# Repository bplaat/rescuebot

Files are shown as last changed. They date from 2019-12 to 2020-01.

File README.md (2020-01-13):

# RescueBot
Technische Informatica - Project 2 (RescueBot) - Group 5

## Slave to Master protocol
Values to receive from nano:

- `distance_to_object` represents the distance the the object in front of the car in cm
- `distance_to_left` represents the distance to first left object / wall in cm
- `distance_to_right` represents the distance to first right object / wall in cm
- `distance_to_ground` represents the distance to the ground in cm
- `ir_left` the value of the ir sensor on the left site as boolean (1 means border found)
- `ir_right` the value of the ir sensor on the right site as boolean (1 means border found)

```
struct slave_to_master {
    uint8_t distance_to_object;
    uint8_t distance_to_left;
    uint8_t distance_to_right;
    uint8_t distance_to_ground;
    uint8_t ir_left;
    uint8_t ir_right;
};
```

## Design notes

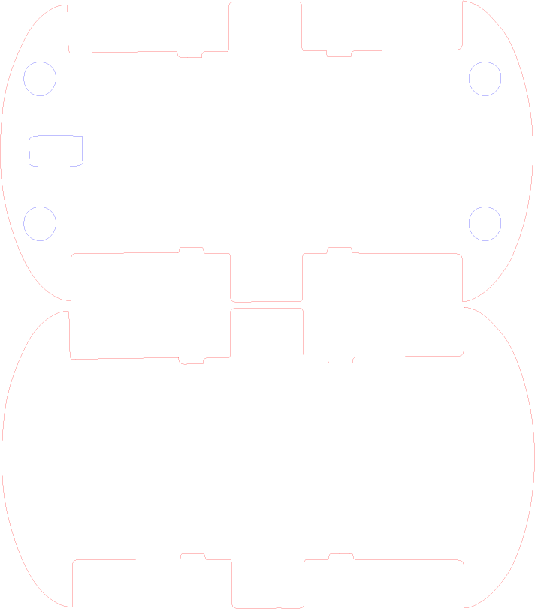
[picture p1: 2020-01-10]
documents/auto design revised.png

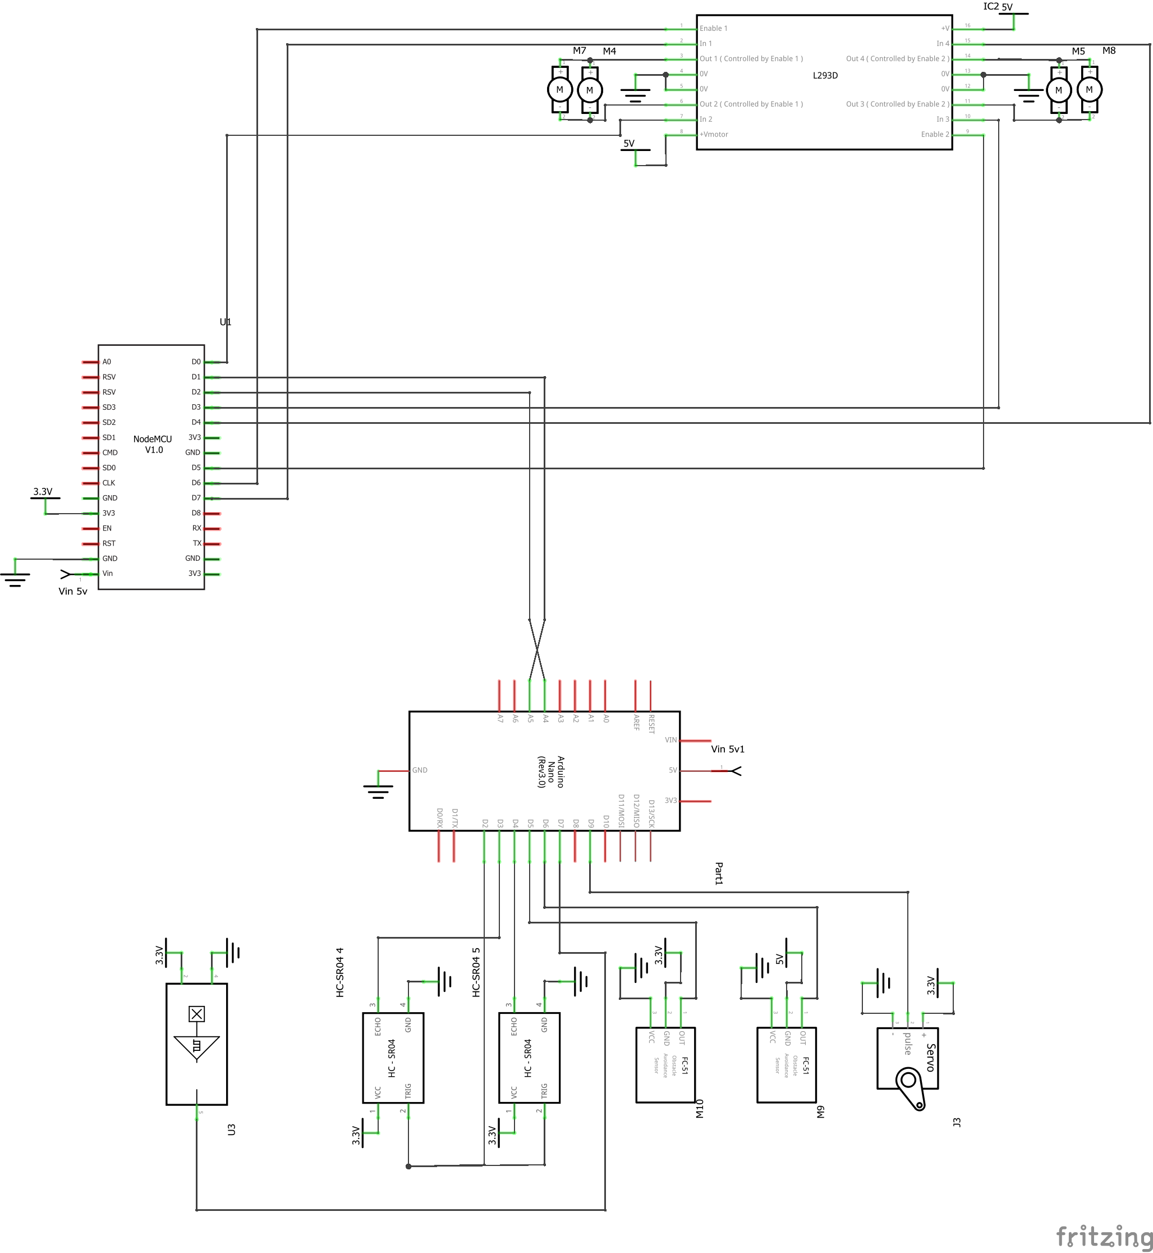
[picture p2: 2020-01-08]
documents/scheme.png

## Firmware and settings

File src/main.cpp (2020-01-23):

// Include the libraries, the config and the website headers
#include <Arduino.h>
#include <ESP8266WiFi.h>
#include <ESP8266WebServer.h>
#include <WebSocketsServer.h>
#include <ArduinoJson.h>
#include <Wire.h>
#include "config.hpp"
#include "website.hpp"

// #############################################################################
// ############################# I2C COMMUNICATION #############################
// #############################################################################

// The i2c variables
#define I2C_ADDRESS 10
#define REQUEST_TIMEOUT 250
#define PROTOCOL_REQUEST_MESSAGE_LENGTH 6
#define PROTOCOL_BORDER_NOT_FOUND 0
#define PROTOCOL_BORDER_FOUND 1

uint32_t request_time;

uint8_t distance_to_object;
uint8_t distance_to_left;
uint8_t distance_to_right;
uint8_t distance_to_ground;
uint8_t ir_left;
uint8_t ir_right;

// A function that request the data and updates some variables
void update_data_from_slave() {
    if (Wire.requestFrom(I2C_ADDRESS, PROTOCOL_REQUEST_MESSAGE_LENGTH) == PROTOCOL_REQUEST_MESSAGE_LENGTH) {
        distance_to_object = Wire.read();
        distance_to_left = Wire.read();
        distance_to_right = Wire.read();
        distance_to_ground = Wire.read();
        ir_left = Wire.read();
        ir_right = Wire.read();

        #ifdef DEBUG
            printf("distance_to_object: %d, distance_to_left: %d, distance_to_right: %d, distance_to_ground: %d, ir_left: %d, ir_right: %d\n",
                distance_to_object, distance_to_left, distance_to_right, distance_to_ground, ir_left, ir_right);
        #endif
    }
}

// A function that ints the i2c and gets the data
void i2c_init() {
    request_time = millis();
    Wire.begin();
    update_data_from_slave();
}

// #############################################################################
// ############################### MOTOR PINS ##################################
// #############################################################################

// The motor pins
#define MOTOR_LEFT_FORWARD_PIN D0
#define MOTOR_LEFT_BACKWARD_PIN D6
#define MOTOR_LEFT_ENABLE_PIN D7

#define MOTOR_RIGHT_FORWARD_PIN D3
#define MOTOR_RIGHT_BACKWARD_PIN D4
#define MOTOR_RIGHT_ENABLE_PIN D5

// Inits the motor pins
void motor_init() {
    pinMode(MOTOR_LEFT_FORWARD_PIN, OUTPUT);
    pinMode(MOTOR_LEFT_BACKWARD_PIN, OUTPUT);
    pinMode(MOTOR_LEFT_ENABLE_PIN, OUTPUT);

    pinMode(MOTOR_RIGHT_FORWARD_PIN, OUTPUT);
    pinMode(MOTOR_RIGHT_BACKWARD_PIN, OUTPUT);
    pinMode(MOTOR_RIGHT_ENABLE_PIN, OUTPUT);
}

// Moves the car forward
void motor_move_forward() {
    digitalWrite(MOTOR_LEFT_FORWARD_PIN, HIGH);
    digitalWrite(MOTOR_LEFT_BACKWARD_PIN, LOW);
    digitalWrite(MOTOR_LEFT_ENABLE_PIN, HIGH);

    digitalWrite(MOTOR_RIGHT_FORWARD_PIN, HIGH);
    digitalWrite(MOTOR_RIGHT_BACKWARD_PIN, LOW);
    digitalWrite(MOTOR_RIGHT_ENABLE_PIN, HIGH);
}

// Turns the car to the left
void motor_turn_left() {
    digitalWrite(MOTOR_LEFT_FORWARD_PIN, HIGH);
    digitalWrite(MOTOR_LEFT_BACKWARD_PIN, LOW);
    digitalWrite(MOTOR_LEFT_ENABLE_PIN, HIGH);

    digitalWrite(MOTOR_RIGHT_FORWARD_PIN, LOW);
    digitalWrite(MOTOR_RIGHT_BACKWARD_PIN, HIGH);
    digitalWrite(MOTOR_RIGHT_ENABLE_PIN, HIGH);
}

// Turns the cars to the right
void motor_turn_right() {
    digitalWrite(MOTOR_LEFT_FORWARD_PIN, LOW);
    digitalWrite(MOTOR_LEFT_BACKWARD_PIN, HIGH);
    digitalWrite(MOTOR_LEFT_ENABLE_PIN, HIGH);

    digitalWrite(MOTOR_RIGHT_FORWARD_PIN, HIGH);
    digitalWrite(MOTOR_RIGHT_BACKWARD_PIN, LOW);
    digitalWrite(MOTOR_RIGHT_ENABLE_PIN, HIGH);
}

// Moves the car backward
void motor_move_backward() {
    digitalWrite(MOTOR_LEFT_FORWARD_PIN, LOW);
    digitalWrite(MOTOR_LEFT_BACKWARD_PIN, HIGH);
    digitalWrite(MOTOR_LEFT_ENABLE_PIN, HIGH);

    digitalWrite(MOTOR_RIGHT_FORWARD_PIN, LOW);
    digitalWrite(MOTOR_RIGHT_BACKWARD_PIN, HIGH);
    digitalWrite(MOTOR_RIGHT_ENABLE_PIN, HIGH);
}

// Stops all motors
void motor_stop() {
    digitalWrite(MOTOR_LEFT_FORWARD_PIN, LOW);
    digitalWrite(MOTOR_LEFT_BACKWARD_PIN, LOW);
    digitalWrite(MOTOR_LEFT_ENABLE_PIN, LOW);

    digitalWrite(MOTOR_RIGHT_FORWARD_PIN, LOW);
    digitalWrite(MOTOR_RIGHT_BACKWARD_PIN, LOW);
    digitalWrite(MOTOR_RIGHT_ENABLE_PIN, LOW);
}

// #############################################################################
// #################################### STATE ##################################
// #############################################################################

// Define function before usage in state code
void broadcast_new_state();

// Variables to hold the last border position
#define BORDER_LEFT 0
#define BORDER_RIGHT 1

uint8_t last_border_position = BORDER_LEFT;

// The different states
#define STATE_STILL 0
#define STATE_MOVE_FORWARD 1

#define STATE_AVOID_LEFT_BORDER 2
#define STATE_AVOID_RIGHT_BORDER 3

#define STATE_AVOID_FRONT_BORDER_MOVE_BACKWARD 4
#define STATE_AVOID_FRONT_BORDER_TURN_LEFT 5
#define STATE_AVOID_FRONT_BORDER_TURN_RIGHT 6

#define STATE_AVOID_OBJECT_TURN_LEFT 7
#define STATE_AVOID_OBJECT_TURN_RIGHT 8

#define STATE_OVERIDE_MOVE_FORWARD 9
#define STATE_OVERIDE_TURN_LEFT 10
#define STATE_OVERIDE_TURN_RIGHT 11
#define STATE_OVERIDE_MOVE_BACKWARD 12

#define STATE_MAGNET_FOUND 13

#define STATE_AVOID_TUNNEL_LEFT 14
#define STATE_AVOID_TUNNEL_RIGHT 15

// The state variables
bool auto_control = false;
uint8_t state = STATE_MOVE_FORWARD;
uint32_t state_time = millis();

// A function that sets the state and reflects it to the motors
void set_state(uint8_t new_state, bool broadcast_to_clients) {
    if (new_state != state) {
        state = new_state;
        state_time = millis();

        // Standard states
        if (state == STATE_STILL) {
            motor_stop();
        }

        if (state == STATE_MOVE_FORWARD) {
            motor_move_forward();
        }

        // Avoid left border
        if (state == STATE_AVOID_LEFT_BORDER) {
            last_border_position = BORDER_LEFT;
            motor_turn_right();
        }

        // Avoid right border
        if (state == STATE_AVOID_RIGHT_BORDER) {
            last_border_position = BORDER_RIGHT;
            motor_turn_left();
        }

        // Avoid front border / cliff
        if (state == STATE_AVOID_FRONT_BORDER_MOVE_BACKWARD) {
            motor_move_backward();
        }

        if (state == STATE_AVOID_FRONT_BORDER_TURN_LEFT) {
            motor_turn_left();
        }

        if (state == STATE_AVOID_FRONT_BORDER_TURN_RIGHT) {
            motor_turn_right();
        }

        // Avoid objects
        if (state == STATE_AVOID_OBJECT_TURN_LEFT) {
            motor_turn_left();
        }

        if (state == STATE_AVOID_OBJECT_TURN_RIGHT) {
            motor_turn_right();
        }

        // Overide motor
        if (state == STATE_OVERIDE_MOVE_FORWARD) {
            motor_move_forward();
        }

        if (state == STATE_OVERIDE_TURN_LEFT) {
            motor_turn_left();
        }

        if (state == STATE_OVERIDE_TURN_RIGHT) {
            motor_turn_right();
        }

        if (state == STATE_OVERIDE_MOVE_BACKWARD) {
            motor_move_backward();
        }

        // Magnet found
        if (state == STATE_MAGNET_FOUND) {
            motor_stop();
        }

        // Tunnel forward
        if (state == STATE_AVOID_TUNNEL_LEFT) {
            motor_turn_right();
        }

        if (state == STATE_AVOID_TUNNEL_RIGHT) {
            motor_turn_left();
        }

        // Broadcast new state to clients
        if (broadcast_to_clients) {
            broadcast_new_state();
        }
    }
}

// A function that updates the state with the data
void update_state() {
    // Calculate time passsed since last state change
    uint32_t time_passed = millis() - state_time;

    // Magent -> Tunnel -> Border -> Object

    #ifdef ACTIVATE_HALL_SENSOR
        // Magnet detection
        uint32_t analog_out = analogRead(HALL_SENSOR_PIN);
        if (analog_out < 561) {
            set_state(STATE_MAGNET_FOUND, true);

            #ifdef DEBUG
                Serial.print("Magnet found: ");
                Serial.println(analog_out);
            #endif
        }

        else {
    #endif

    // Tunnel dection
    if (distance_to_left <= 5) {
        set_state(STATE_AVOID_TUNNEL_LEFT, true);
    }
    else if (distance_to_right <= 5) {
        set_state(STATE_AVOID_TUNNEL_RIGHT, true);
    }

    else {
        // Front border / cliff detection
        if ((ir_left == PROTOCOL_BORDER_FOUND && ir_right == PROTOCOL_BORDER_FOUND) || distance_to_ground > 10) {
            set_state(STATE_AVOID_FRONT_BORDER_MOVE_BACKWARD, true);
        }

        // Left border detection
        else if (ir_left == PROTOCOL_BORDER_FOUND) {
            set_state(STATE_AVOID_LEFT_BORDER, true);
        }

        // Right border detection
        else if (ir_right == PROTOCOL_BORDER_FOUND) {
            set_state(STATE_AVOID_RIGHT_BORDER, true);
        }

        else {
            // Object dection
            if (distance_to_object <= 20) {
                if (last_border_position == BORDER_LEFT) {
                    set_state(STATE_AVOID_OBJECT_TURN_RIGHT, true);
                }
                if (last_border_position == BORDER_RIGHT) {
                    set_state(STATE_AVOID_OBJECT_TURN_LEFT, true);
                }
            }
        }
    }

    // Tunnel deactivivation
    if (state == STATE_AVOID_TUNNEL_LEFT && distance_to_left > 5) {
        set_state(STATE_MOVE_FORWARD, true);
    }

    if (state == STATE_AVOID_TUNNEL_RIGHT && distance_to_right > 5) {
        set_state(STATE_MOVE_FORWARD, true);
    }

    // Front border deactivivation
    if (state == STATE_AVOID_FRONT_BORDER_MOVE_BACKWARD && time_passed > 2500) {
        if (last_border_position == BORDER_LEFT) {
            set_state(STATE_AVOID_FRONT_BORDER_TURN_RIGHT, true);
        }
        if (last_border_position == BORDER_RIGHT) {
            set_state(STATE_AVOID_FRONT_BORDER_TURN_LEFT, true);
        }
    }

    if (state == STATE_AVOID_FRONT_BORDER_TURN_RIGHT && time_passed > 2500) {
        set_state(STATE_MOVE_FORWARD, true);
    }

    if (state == STATE_AVOID_FRONT_BORDER_TURN_LEFT && time_passed > 2500) {
        set_state(STATE_MOVE_FORWARD, true);
    }

    // Left border deactivivation
    if (state == STATE_AVOID_LEFT_BORDER && ir_left == PROTOCOL_BORDER_NOT_FOUND) {
        set_state(STATE_MOVE_FORWARD, true);
    }

    // Right border deactivivation
    if (state == STATE_AVOID_RIGHT_BORDER && ir_left == PROTOCOL_BORDER_NOT_FOUND) {
        set_state(STATE_MOVE_FORWARD, true);
    }

    // Object deactivivation
    if (state == STATE_AVOID_OBJECT_TURN_LEFT && time_passed > 2500) {
        set_state(STATE_MOVE_FORWARD, true);
    }

    if (state == STATE_AVOID_OBJECT_TURN_RIGHT && time_passed > 2500) {
        set_state(STATE_MOVE_FORWARD, true);
    }

    #ifdef ACTIVATE_HALL_SENSOR
        }
    #endif
}

// #############################################################################
// ############################# WIFI / WEB SERVER #############################
// #############################################################################

// A function that connects to wifi via the config settings
void wifi_connect() {
    Serial.print("\nConnecting to ");
    Serial.print(wifi_ssid);
    Serial.println("...");

    WiFi.begin(wifi_ssid, wifi_password);
    while (WiFi.status() != WL_CONNECTED) {
        Serial.print(".");
        delay(500);
    }
    Serial.println();

    Serial.print("RescueBot ");
    Serial.print(rescuebot_name);
    Serial.println(" connected!");
    Serial.print("IP address: ");
    Serial.println(WiFi.localIP());
}

// The web server object
ESP8266WebServer webserver(80);

// A function that inits the webs server
void webserver_init() {
    // Return the web interface when you go to the root path
    webserver.on("/", []() {
        webserver.send(200, "text/html", src_website_html, src_website_html_len);
    });

    // Begin the web server
    webserver.begin();
}

// The web socket server object
WebSocketsServer websocket(81);

// The websocket event handler function
void websocket_event(uint8_t num, WStype_t type, const uint8_t *payload, size_t length){
    if (type == WStype_CONNECTED) {
        // Send data to new client
        StaticJsonDocument<256> doc;
        String client_message;
        doc["rescuebot_name"] = rescuebot_name;
        doc["state"] = state;
        doc["last_border_position"] = last_border_position;
        doc["auto_control"] = auto_control;
        serializeJson(doc, client_message);
        websocket.sendTXT(num, client_message);
    }

    if (type == WStype_TEXT) {
        // Update data from json message
        StaticJsonDocument<256> doc;
        deserializeJson(doc, payload, length);
        set_state(doc["state"], false);
        auto_control = doc["auto_control"];

        // Send change message to all clients
        websocket.broadcastTXT(payload, length);
    }
}

// Function that broadcasts the new state to the clients
void broadcast_new_state() {
    StaticJsonDocument<256> doc;
    String client_message;
    doc["state"] = state;
    doc["last_border_position"] = last_border_position;
    serializeJson(doc, client_message);
    websocket.broadcastTXT(client_message);
}

// Init the websockets server
void websocket_init() {
    websocket.begin();
    websocket.onEvent(websocket_event);
}

// #############################################################################
// ######################## ARDUINO LIBRARY SETUP & LOOP #######################
// #############################################################################

// The start of our program
void setup() {
    // Init the serial output
    Serial.begin(9600);

    // Init all the things
    #ifdef ACTIVATE_HALL_SENSOR
        pinMode(HALL_SENSOR_PIN, OUTPUT);
    #endif
    i2c_init();
    motor_init();
    wifi_connect();
    webserver_init();
    websocket_init();
}

// The program loop
void loop() {
    // Handle websocket clients
    websocket.loop();

    // Handle any http clients
    webserver.handleClient();

    // Get new data from the slave with a timeout
    if (millis() - request_time > REQUEST_TIMEOUT) {
        request_time = millis();
        update_data_from_slave();
    }

    // Update the state with the data when auto control is on
    if (auto_control) {
        update_state();
    }
}

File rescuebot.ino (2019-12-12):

#include <ESP8266WiFi.h>
#include <ESP8266WebServer.h>
#include "config.h"
#include "controls.h"

#define MOTOR_LEFT_FORWARD_PIN D0
#define MOTOR_LEFT_BACKWARD_PIN D1
#define MOTOR_LEFT_ENABLE_PIN D2

#define MOTOR_RIGHT_FORWARD_PIN D3
#define MOTOR_RIGHT_BACKWARD_PIN D4
#define MOTOR_RIGHT_ENABLE_PIN D5

/*#define IR_LEFT_PIN D6
#define IR_RIGHT_PIN D7
#define PULSE_SERVO_PIN D8

#define TRIGGER_PIN D9
#define ECHO_PIN_LOW_MOUNTED 10
#define ECHO_PIN_HIGH_MOUNTED A0
*/

void motor_move_forward() {
    digitalWrite(MOTOR_LEFT_FORWARD_PIN, HIGH);
    digitalWrite(MOTOR_LEFT_BACKWARD_PIN, LOW);
    digitalWrite(MOTOR_LEFT_ENABLE_PIN, HIGH);

    digitalWrite(MOTOR_RIGHT_FORWARD_PIN, HIGH);
    digitalWrite(MOTOR_RIGHT_BACKWARD_PIN, LOW);
    digitalWrite(MOTOR_RIGHT_ENABLE_PIN, HIGH);
}

void motor_move_backward() {
    digitalWrite(MOTOR_LEFT_FORWARD_PIN, LOW);
    digitalWrite(MOTOR_LEFT_BACKWARD_PIN, HIGH);
    digitalWrite(MOTOR_LEFT_ENABLE_PIN, HIGH);

    digitalWrite(MOTOR_RIGHT_FORWARD_PIN, LOW);
    digitalWrite(MOTOR_RIGHT_BACKWARD_PIN, HIGH);
    digitalWrite(MOTOR_RIGHT_ENABLE_PIN, HIGH);
}

void motor_turn_left() {
    digitalWrite(MOTOR_LEFT_ENABLE_PIN, LOW);

    digitalWrite(MOTOR_RIGHT_FORWARD_PIN, HIGH);
    digitalWrite(MOTOR_RIGHT_BACKWARD_PIN, LOW);
    digitalWrite(MOTOR_RIGHT_ENABLE_PIN, HIGH);
}

void motor_turn_right() {
    digitalWrite(MOTOR_LEFT_FORWARD_PIN, HIGH);
    digitalWrite(MOTOR_LEFT_BACKWARD_PIN, LOW);
    digitalWrite(MOTOR_LEFT_ENABLE_PIN, HIGH);

    digitalWrite(MOTOR_RIGHT_ENABLE_PIN, LOW);
}

void motor_stop() {
    digitalWrite(MOTOR_LEFT_ENABLE_PIN, LOW);
    digitalWrite(MOTOR_RIGHT_ENABLE_PIN, LOW);
}

ESP8266WebServer server(80);

void setup() {
    Serial.begin(115200);

    pinMode(MOTOR_LEFT_FORWARD_PIN, OUTPUT);
    pinMode(MOTOR_LEFT_BACKWARD_PIN, OUTPUT);
    pinMode(MOTOR_LEFT_ENABLE_PIN, OUTPUT);

    pinMode(MOTOR_RIGHT_FORWARD_PIN, OUTPUT);
    pinMode(MOTOR_RIGHT_BACKWARD_PIN, OUTPUT);
    pinMode(MOTOR_RIGHT_ENABLE_PIN, OUTPUT);

    /*
    pinMode(PULSE_SERVO_PIN, OUTPUT);

    pinMode(ECHO_PIN_LOW_MOUNTED, INPUT);
    pinMode(ECHO_PIN_HIGH_MOUNTED, INPUT);
    //pinMode(TRIGGER_PIN, OUTPUT);

    pinMode(IR_OUT_RIGHT_PIN, INPUT);
    pinMode(IR_OUT_LEFT_PIN, INPUT);
    */

    Serial.print("\nConnecting to ");
    Serial.print(wifi_ssid);
    Serial.println("...");
    WiFi.begin(wifi_ssid, wifi_password);
    while (WiFi.status() != WL_CONNECTED) {
        Serial.print(".");
        delay(500);
    }
    Serial.println("\nConnected");

    Serial.print("IP address: ");
    Serial.println(WiFi.localIP());

    server.on("/", []() {
        server.send(200, "text/html", controls_html);
    });

    server.on("/api/update_motor_state", []() {
        String motor_state = server.arg("motor_state");

        if (motor_state == "forward") {
            motor_move_forward();
        }
        if (motor_state == "left") {
            motor_turn_left();
        }
        if (motor_state == "right") {
            motor_turn_right();
        }
        if (motor_state == "backward") {
            motor_move_backward();
        }
        if (motor_state == "stop") {
            motor_stop();
        }

        server.send(200, "application/json", "{\"message\":\"succesfull\"}");
    });

    server.begin();
}

void loop() {
    server.handleClient();
}

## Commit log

2019-11-27 Add motor control functions
2019-11-27 Add motor control via json api
2019-11-27 Adding fritzing scheme
    [fritzing.fzz]
2019-11-27 adding power suply
    [scheme.fzz]
2019-11-28 update for schematics
    [scheme.fzz]
2019-11-28 fix in schema
    [scheme.fzz]
2019-11-28 adding sensoren to the scheme
    [scheme.fzz]
2019-11-29 change pin name
    [scheme.fzz]
2019-11-29 adding pin defenitions
2019-11-29 adding test program for servo motor
2019-11-29 fix in fritzing
    [scheme.fzz]
2019-12-04 adding hall sensor
    [scheme.fzz]
2019-12-05 adding Vin pin
2019-12-05 Adding wires
    [scheme.fzz]
2019-12-12 scheme with using one H-brige
    [scheme.fzz]
2019-12-17 Switch to platform io
    [scheme.fzz]
2020-01-07 Adding I2C to master and slave
2020-01-08 Adding arduino nano to the scheme.
    [scheme.fzz]
2020-01-09 Servo and Sensors working.
2020-01-10 Add a name config propety and some bug fixes in the web interface
    [main.cpp]
2020-01-13 change motor pins.
2020-01-16 Put wire input to serial.
2020-01-16 Make IR sensor digital.
2020-01-17 Fix web interface bugs
    [main.cpp]
2020-01-17 Adding hall sensor, fixing bug in set_state method
    [main.cpp]
2020-01-23 Change to hall sensor readout.
